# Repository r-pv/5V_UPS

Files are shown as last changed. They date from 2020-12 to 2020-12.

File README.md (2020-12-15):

# 5V_UPS

A real 5V Uninterruptible Power Supply (UPS) based on the [MP2637](https://www.monolithicpower.com/en/mp2637.html) IC, supporting 4.2V and 4.35V LiION/LiPO batteries. The design it's practically the design layout recomended by the manufacturer just with a few minor differences.

The board it's 30x30mm and it's capable of 2.5A battery charge and 2.4A boost output.

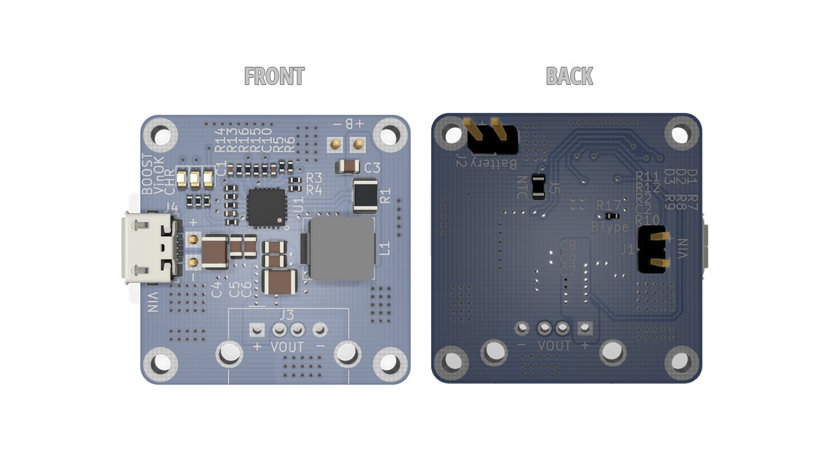
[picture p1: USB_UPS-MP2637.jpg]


## Working as a proper UPS:

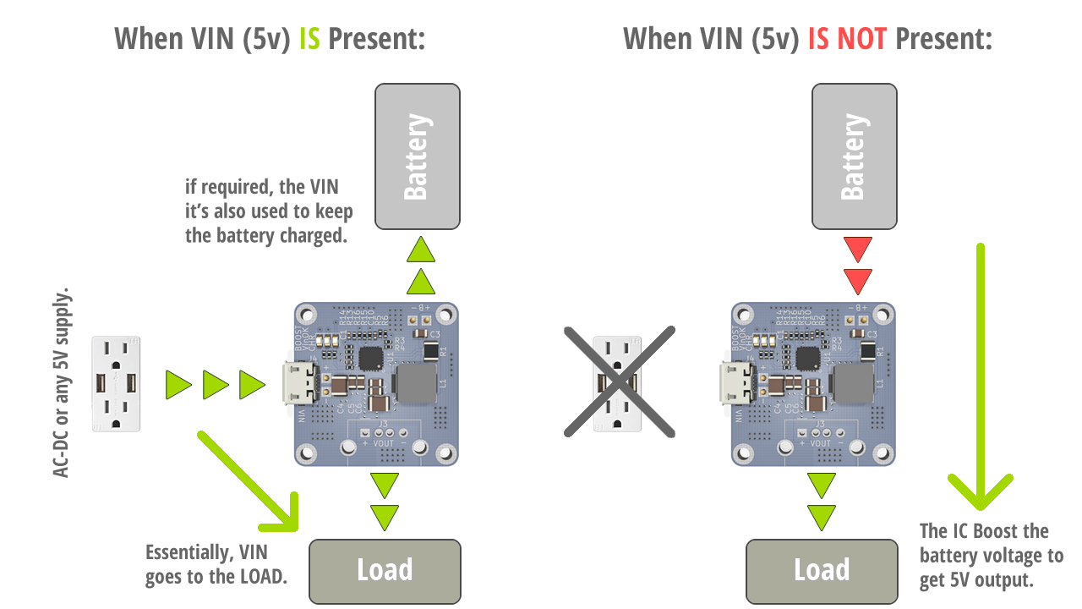
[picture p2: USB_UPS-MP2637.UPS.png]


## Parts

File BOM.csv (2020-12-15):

Ref | Value | Footprint
C1 | 100nF | Capacitor_SMD:C_0402_1005Metric
C2 | 100nF | Capacitor_SMD:C_0402_1005Metric
C3 | 47uF | Capacitor_SMD:C_0805_2012Metric
C4 | 100uF | Capacitor_SMD:C_1210_3225Metric
C5 | 47uF | Capacitor_SMD:C_0805_2012Metric
C6 | 22uF | Capacitor_SMD:C_0805_2012Metric
C7 | 100uF | Capacitor_SMD:C_1210_3225Metric
C8 | 47uF | Capacitor_SMD:C_0805_2012Metric
C9 | 22uF | Capacitor_SMD:C_0805_2012Metric
C10 | 120pF | Capacitor_SMD:C_0402_1005Metric
D1 | LED | LED_SMD:LED_0603_1608Metric
D2 | LED | LED_SMD:LED_0603_1608Metric
D3 | LED | LED_SMD:LED_0603_1608Metric
H1 | Mounting Hole M2 | MountingHole:MountingHole_2.2mm_M2_DIN965_Pad
H2 | Mounting Hole M2 | MountingHole:MountingHole_2.2mm_M2_DIN965_Pad
H3 | Mounting Hole M2 | MountingHole:MountingHole_2.2mm_M2_DIN965_Pad
H4 | Mounting Hole M2 | MountingHole:MountingHole_2.2mm_M2_DIN965_Pad
J1 | VIN | Connector_PinHeader_2.54mm:PinHeader_1x02_P2.54mm_Vertical
J2 | Battery | Connector_PinHeader_2.54mm:PinHeader_1x02_P2.54mm_Vertical
J3 | USB_OUT | Connector_USB:USB_A_Molex_67643_Horizontal
J4 | USB_IN | Connector_USB:USB_Micro-B_Molex_47346-0001
J5 | NTC | Resistor_SMD:R_0805_2012Metric
L1 | 2.2uH | MHCI06030-2R2M-R8, 0603
R1 | 0R02 | Resistor_SMD:R_1210_3225Metric
R2 | 20K | Resistor_SMD:R_0402_1005Metric
R3 | 120K | Resistor_SMD:R_0402_1005Metric
R4 | 100K | Resistor_SMD:R_0402_1005Metric
R5 | 10K | Resistor_SMD:R_0402_1005Metric
R6 | 10K | Resistor_SMD:R_0402_1005Metric
R7 | 4K7 | Resistor_SMD:R_0402_1005Metric
R8 | 4K7 | Resistor_SMD:R_0402_1005Metric
R9 | 4K7 | Resistor_SMD:R_0402_1005Metric
R10 | 4K7 | Resistor_SMD:R_0402_1005Metric
R11 | 75K | Resistor_SMD:R_0402_1005Metric
R12 | 15K | Resistor_SMD:R_0402_1005Metric
R13 | 68K | Resistor_SMD:R_0402_1005Metric
R14 | 22K | Resistor_SMD:R_0402_1005Metric
R15 | 33K | Resistor_SMD:R_0402_1005Metric
R16 | 10K | Resistor_SMD:R_0402_1005Metric
R17 | 0R | Resistor_SMD:R_0402_1005Metric
U1 | MP2637 | QFN-24_4x4mm-MP

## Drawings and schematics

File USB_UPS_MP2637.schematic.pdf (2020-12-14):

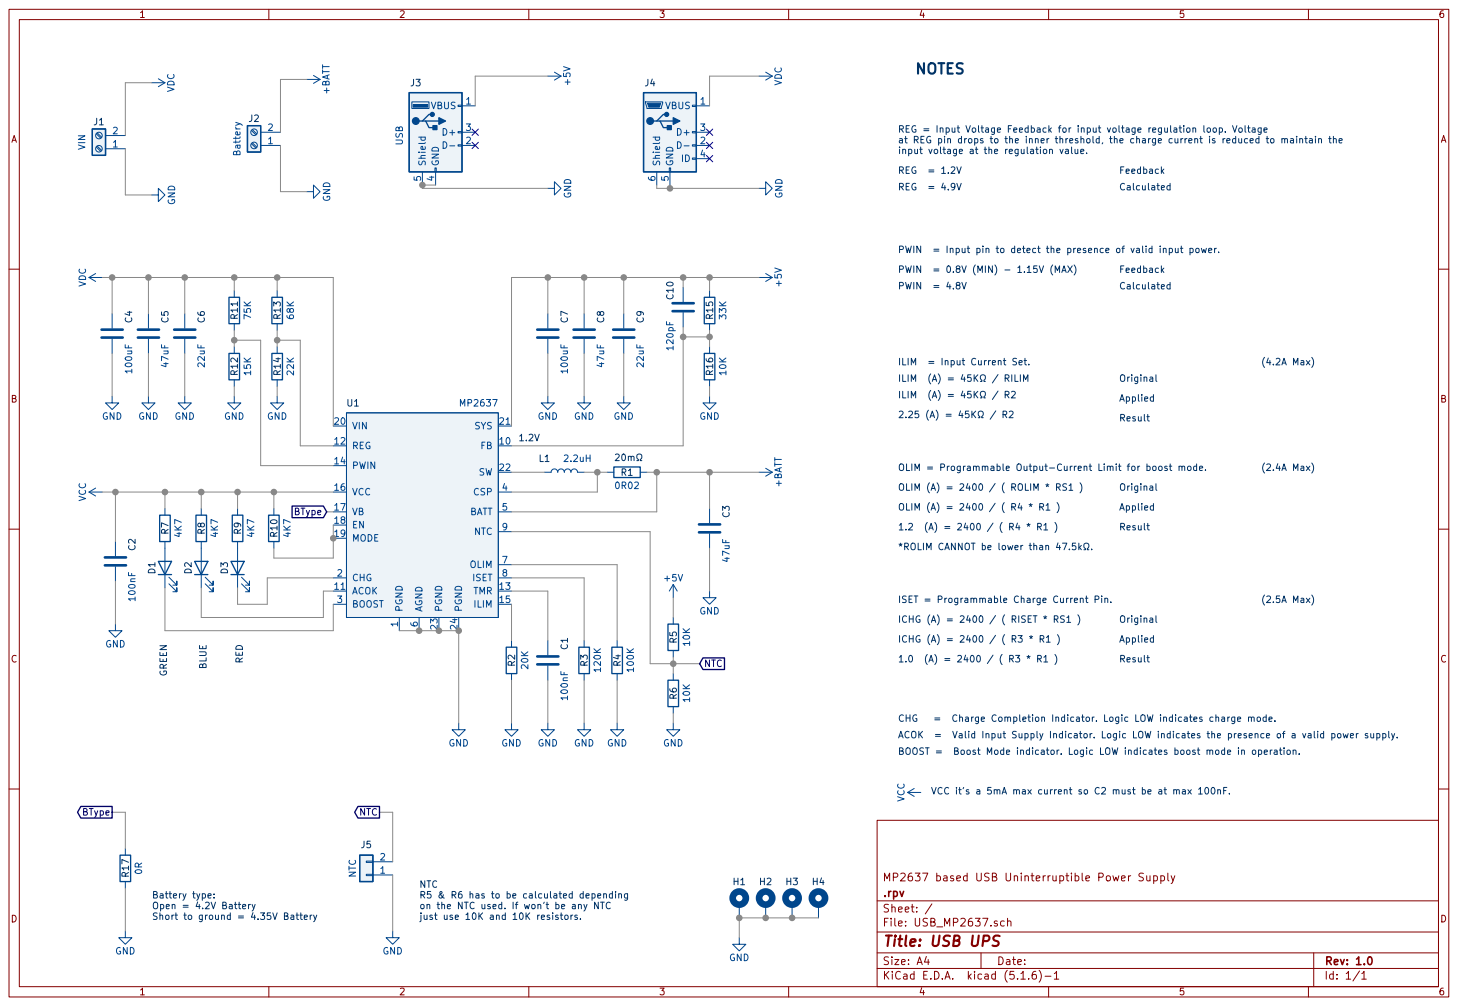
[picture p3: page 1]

REG = Input Voltage Feedback for input voltage regulation loop. Voltage
at REG pin drops to the inner threshold, the charge current is reduced to maintain the
input voltage at the regulation value. REG = 1.2V

PWIN = Input pin to detect the presence of valid input power.

ILIM = Input Current Set.
ILIM (A) = 45K / RILIM

1 FB 10 ACOK 11 REG 12 TMR 13 PWIN 14

OLIM = Programmable Output-Current Limit for boost mode.
OLIM (A) = 2400 / ( ROLIM * RS1 )
*ROLIM CANNOT be lower than 47.5k.

ISET = Programmable Charge Current Pin.
ICHG (A) = 2400 / ( RISET * RS1 )
ICHG (A) = 2400 / ( R3 * R1 )

CHG = Charge Completion Indicator. Logic LOW indicates charge mode.
ACOK = Valid Input Supply Indicator. Logic LOW indicates the presence of a valid power supply.
BOOST = Boost Mode indicator. Logic LOW indicates boost mode in operation.

NTC
R5 & R6 has to be calculated depending
on the NTC used. If won't be any NTC

Battery type:
Open = 4.2V Battery
Short to ground = 4.35V Battery

File: USB_MP2637.sch Sheet: /
Id: 1/1 Title: USB UPS

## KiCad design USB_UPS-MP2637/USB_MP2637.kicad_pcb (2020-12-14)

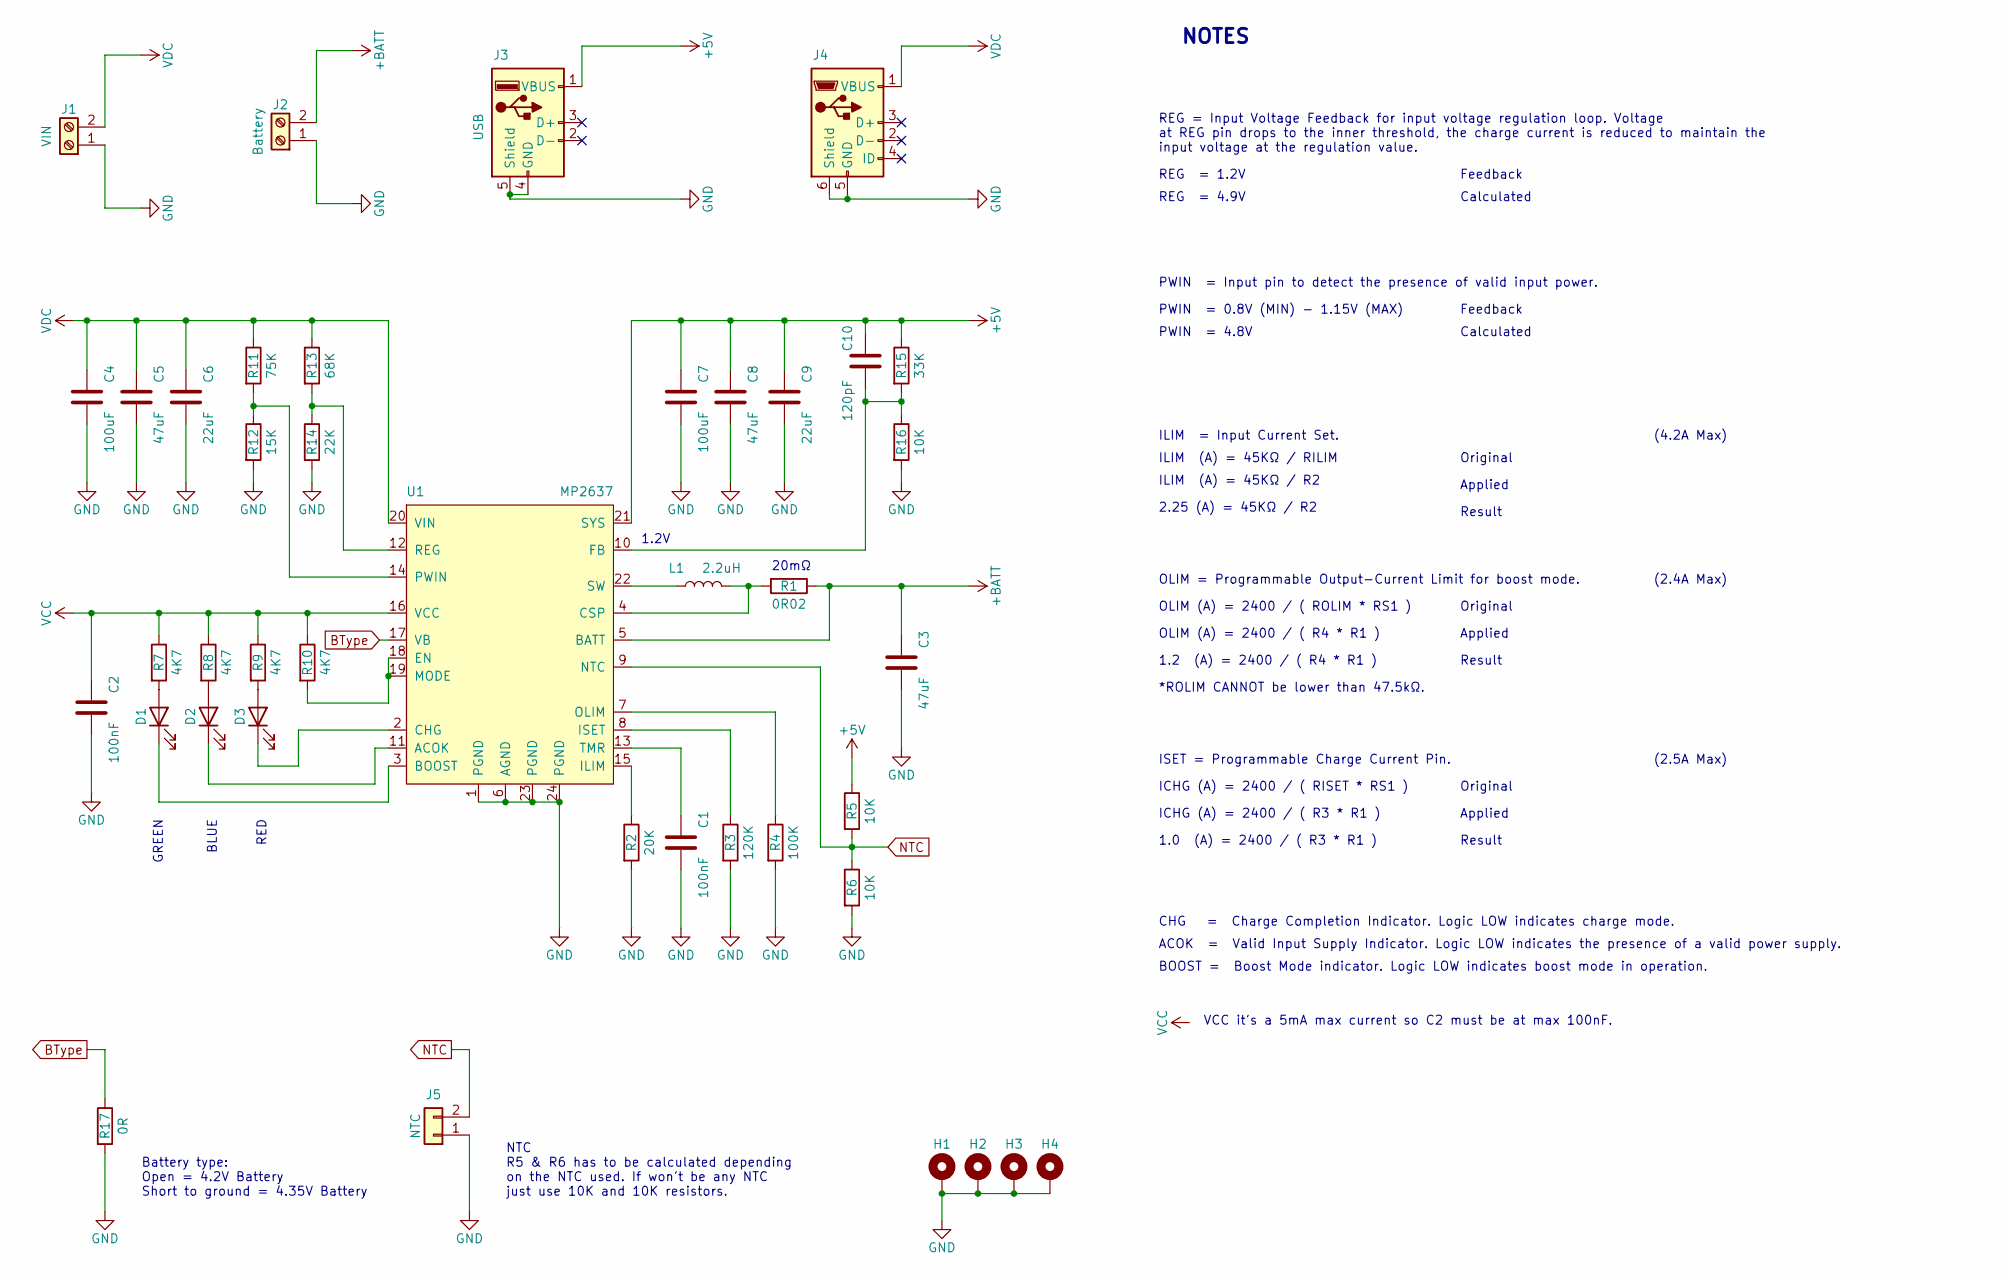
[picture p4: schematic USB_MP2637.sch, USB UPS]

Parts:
C1, C2: 100nF; C_0402_1005Metric
C3, C5, C8: 47uF; C_0805_2012Metric
C4, C7: 100uF; C_1210_3225Metric
C6, C9: 22uF; C_0805_2012Metric
C10: 120pF; C_0402_1005Metric
D1, D2, D3: LED_0603_1608Metric
H1, H2, H3, H4: MountingHole_2.2mm_M2_DIN965_Pad
J1: VIN; PinHeader_1x02_P2.54mm_Vertical
J2: Battery; PinHeader_1x02_P2.54mm_Vertical
J3: USB; USB_A_Molex_67643_Horizontal
J4: USB_Micro-B_Molex_47346-0001
J5: NTC; R_0805_2012Metric
L1: 2.2uH; Inductor-0603
R1: 0R02; R_1210_3225Metric
R2: 20K; R_0402_1005Metric
R3: 120K; R_0402_1005Metric
R4: 100K; R_0402_1005Metric
R5, R6, R16: 10K; R_0402_1005Metric
R7, R8, R9, R10: 4K7; R_0402_1005Metric
R11: 75K; R_0402_1005Metric
R12: 15K; R_0402_1005Metric
R13: 68K; R_0402_1005Metric
R14: 22K; R_0402_1005Metric
R15: 33K; R_0402_1005Metric
R17: 0R; R_0402_1005Metric
U1: MP2637; QFN-24_4x4mm-MP

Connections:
+5V: C7.1, C8.1, C9.1, C10.1, J3.1 (VBUS), R5.1, R15.1, U1.21 (SYS)
+BATT: C3.1, J2.2, R1.1, U1.5 (BATT)
BType: R17.1, U1.17 (VB)
GND: C1.2, C2.2, C3.2, C4.2, C5.2, C6.2, C7.2, C8.2, C9.2, H1.1, H2.1, H3.1, H4.1, J1.1, J2.1, J3.4 (GND), J3.5 (Shield), J4.5 (GND), J4.6 (Shield), J5.1, R2.2, R3.2, R4.2, R6.2, R12.2, R14.2, R16.2, R17.2, U1.1 (PGND), U1.6 (AGND), U1.23 (PGND), U1.24 (PGND)
NTC: J5.2, R5.2, R6.1, U1.9 (NTC)
unnamed: C1.1, U1.13 (TMR)
unnamed: C10.2, R15.2, R16.1, U1.10 (FB)
unnamed: D1.1 (K), U1.3 (BOOST)
unnamed: D1.2 (A), R7.2
unnamed: D2.1 (K), U1.11 (ACOK)
unnamed: D2.2 (A), R8.2
unnamed: D3.1 (K), U1.2 (CHG)
unnamed: D3.2 (A), R9.2
unnamed: L1.1, U1.22 (SW)
unnamed: L1.2, R1.2, U1.4 (CSP)
unnamed: R2.1, U1.15 (ILIM)
unnamed: R3.1, U1.8 (ISET)
unnamed: R4.1, U1.7 (OLIM)
unnamed: R10.2, U1.18 (EN), U1.19 (MODE)
unnamed: R11.2, R12.1, U1.14 (PWIN)
unnamed: R13.2, R14.1, U1.12 (REG)
VCC: C2.1, R7.1, R8.1, R9.1, R10.1, U1.16 (VCC)
VDC: C4.1, C5.1, C6.1, J1.2, J4.1 (VBUS), R11.1, R13.1, U1.20 (VIN)

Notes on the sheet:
OLIM (A) = 2400 / ( ROLIM * RS1 )
ICHG (A) = 2400 / ( RISET * RS1 )
ILIM (A) = 45KΩ / RILIM
1.2V
ILIM = Input Current Set.
OLIM = Programmable Output-Current Limit for boost mode.
ISET = Programmable Charge Current Pin.
ICHG (A) = 2400 / ( R3 * R1 )
1.0 (A) = 2400 / ( R3 * R1 )
Original
Applied
Result
OLIM (A) = 2400 / ( R4 * R1 )
1.2 (A) = 2400 / ( R4 * R1 )
ILIM (A) = 45KΩ / R2
2.25 (A) = 45KΩ / R2
REG = 1.2V
REG = Input Voltage Feedback for input voltage regulation loop. Voltage at REG pin drops to the inner threshold, the charge current is reduced to maintain the input voltage at the regulation value.
PWIN = Input pin to detect the presence of valid input power.
REG = 4.9V
Feedback
Calculated
PWIN = 0.8V (MIN) - 1.15V (MAX)
PWIN = 4.8V
*ROLIM CANNOT be lower than 47.5kΩ.
CHG = Charge Completion Indicator. Logic LOW indicates charge mode.
RED
BLUE
GREEN
ACOK = Valid Input Supply Indicator. Logic LOW indicates the presence of a valid power supply.
BOOST = Boost Mode indicator. Logic LOW indicates boost mode in operation.
NOTES
Battery type: Open = 4.2V Battery Short to ground = 4.35V Battery
(2.5A Max)
(2.4A Max)
(4.2A Max)
20mΩ
NTC R5 & R6 has to be calculated depending on the NTC used. If won't be any NTC just use 10K and 10K resistors.
VCC it's a 5mA max current so C2 must be at max 100nF.

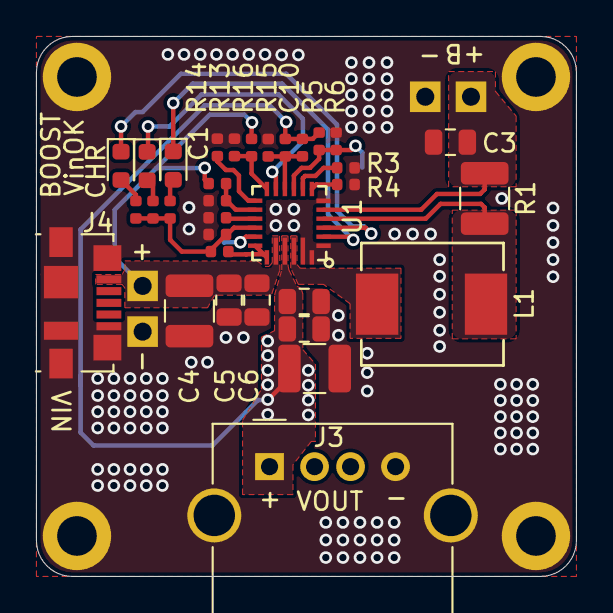
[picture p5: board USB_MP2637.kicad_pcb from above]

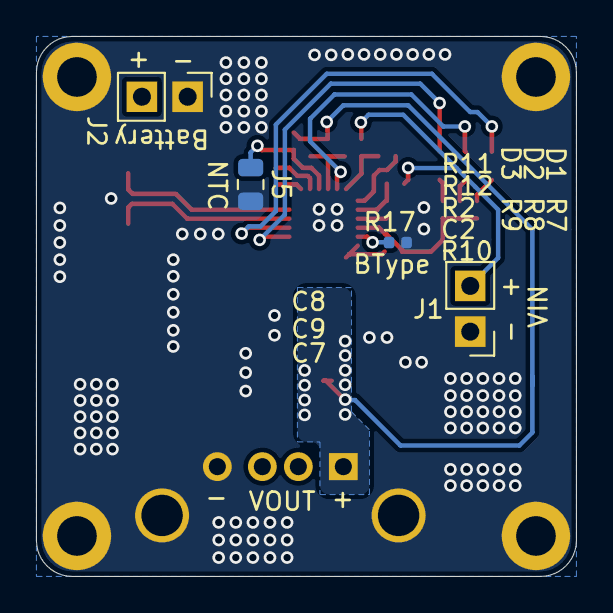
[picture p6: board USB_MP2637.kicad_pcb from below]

Board: 2 copper layers, 30.0 x 30.0 mm, 41 parts (4 on the bottom side), 23 nets.
